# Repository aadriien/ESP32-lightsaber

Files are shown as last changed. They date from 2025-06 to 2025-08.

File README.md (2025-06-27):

# 🪐🤺 Lightsaber

## Description

Introducing... a homemade **lightsaber**, powered by an ESP32 microcontroller! 

This project is still a **work in progress**, so please hang tight while I get things going.

## How It Works

Start by clicking the joystick. This will activate the lightsaber with a cool sound effect (lightspeed)! 

Maneuver the joystick to move between colors. Once you've found a color you like, hold that spot / angle, and click the joystick as you would a button. Keep your ears open for a themed sound corresponding to that specific color! 

To change the blade's hue, angle the joystick button, give it another click, and you'll have returned to "color selection mode". 

When you're ready to deactivate the lightsaber, simply click the joystick again and watch as the lights recede. Listen closely for a message as you go!

## Electronics / Pieces

1. **ESP32-WROOM-32**: microcontroller (logic)
2. **Addressable LED strip (WS2812B)**: lightsaber blade
    - individual LED manipulation 
    - actuator — output
3. **Joystick module**: lightsaber (de)activation
    - range of x, y values to map (+ button)
    - sensor — input
4. **9V battery + clip**: power source
5. **Power supply module**: 5V / 3.3V output converter
6. **Others ad hoc**: cables, wires, resistors, etc

## Tools / Tech

1. **C++**: code running on device
2. **Python**: code to play themed sounds
    - connects via serial monitor
    - using `playsound` library
    - with `PyObjC` to run efficiently
3. **PlatformIO**: embedded development toolset
    - VS Code extension
    - cross-platform, cross-architecture
    - debugger, static analysis, unit testing, etc
    - project configs (build env, dependencies)

## Features

- **⭐️ Lightsaber (de)activation**: Exciting visual effects with sequential LEDs.
- **🎨 Customizable saber blade**: Highly flexible color wheel selection via joystick.

- **🔒 Color locking ability**: Option to hold selected color in place with joystick button.
- **🎵 Themed sound effects**: Music and phrases to match colors and saber (de)activation.

## Video Demos

Video demo of lightsaber activation and color selection

## Example Images

🎮 Wiring View   |   🌈 Lightsaber LED Strip   |   🔌 Wiring Above
:-------------------------:|:-------------------------:|:-------------------------:
Example image of front wiring view  |  Example image of saber LED strip  |  Example image of above wiring view

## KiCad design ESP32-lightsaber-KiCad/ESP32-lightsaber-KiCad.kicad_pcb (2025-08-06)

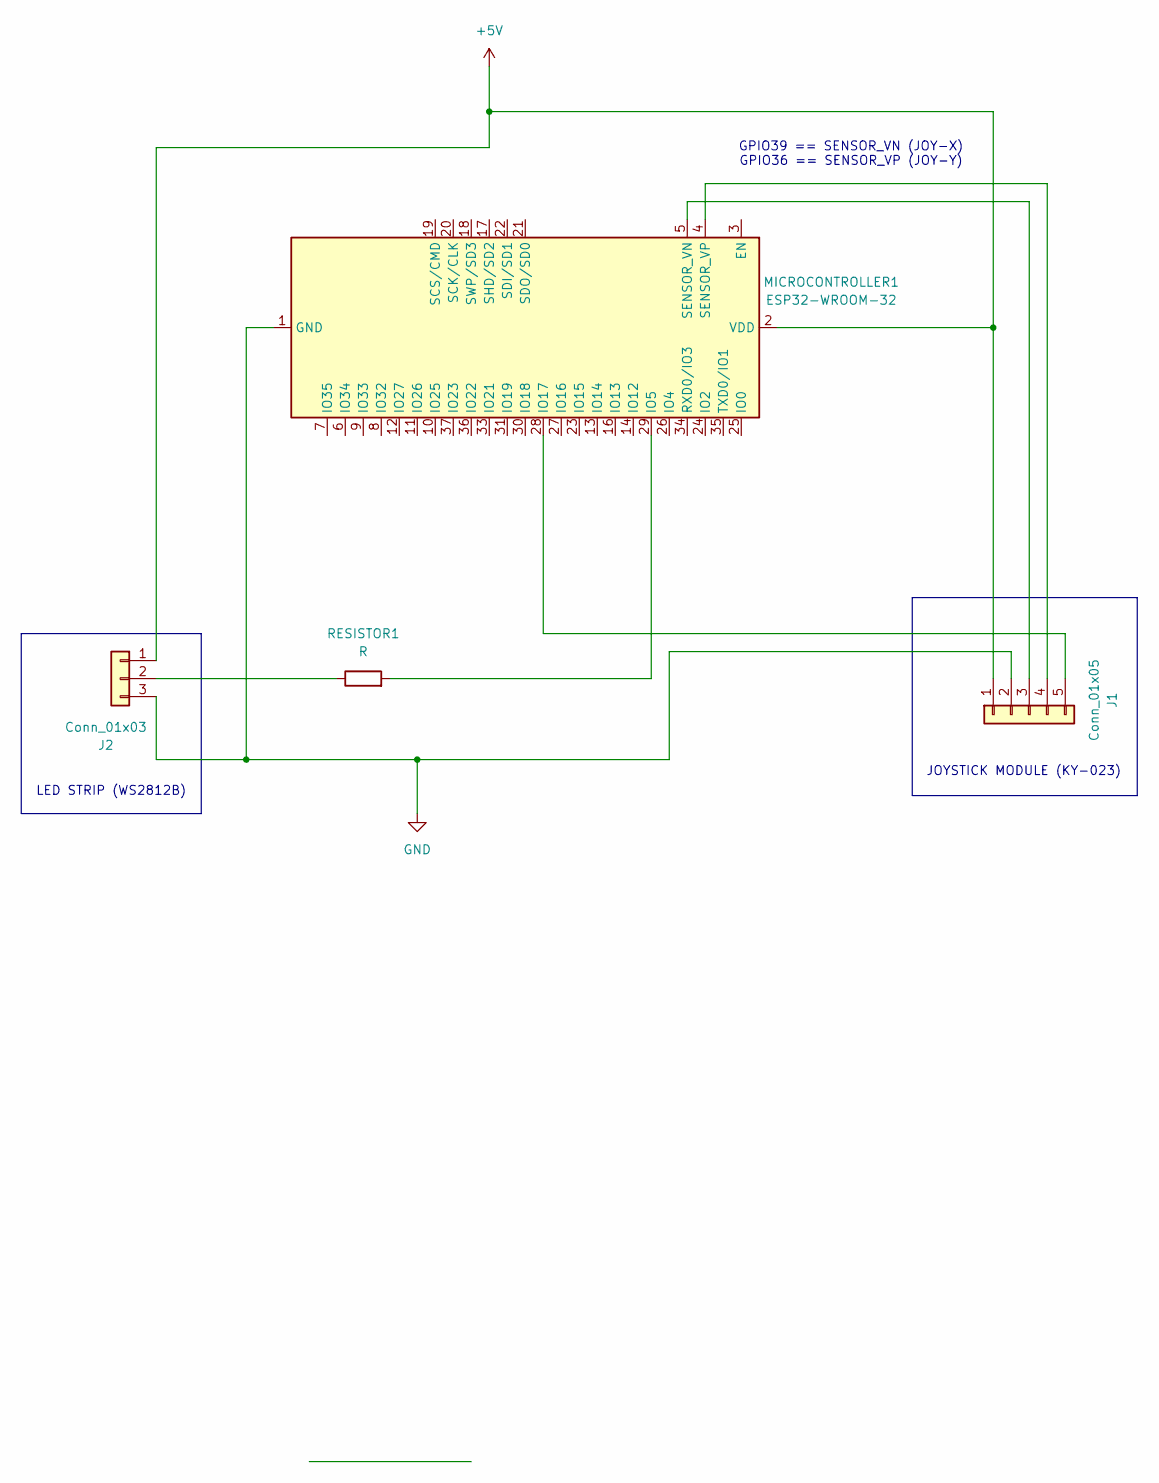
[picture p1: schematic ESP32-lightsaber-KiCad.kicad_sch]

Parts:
J1: Conn_01x05; PinHeader_1x05_P2.54mm_Vertical
J2: Conn_01x03; PinHeader_1x03_P2.54mm_Vertical
MICROCONTROLLER1: ESP32-WROOM-32
RESISTOR1: R; R_0805_2012Metric

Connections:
+5V: J1.1, J2.1, MICROCONTROLLER1.2 (VDD)
GND: J1.2, J2.3, MICROCONTROLLER1.1 (GND), MICROCONTROLLER1.15 (GND), MICROCONTROLLER1.38 (GND), MICROCONTROLLER1.39 (GND)
unnamed: J1.3, MICROCONTROLLER1.5 (SENSOR_VN)
unnamed: J1.4, MICROCONTROLLER1.4 (SENSOR_VP)
unnamed: J1.5, MICROCONTROLLER1.28 (IO17)
unnamed: J2.2, RESISTOR1.1
unnamed: MICROCONTROLLER1.29 (IO5), RESISTOR1.2

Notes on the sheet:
LED STRIP (WS2812B)
GPIO39 == SENSOR_VN (JOY-X) GPIO36 == SENSOR_VP (JOY-Y)
JOYSTICK MODULE (KY-023)

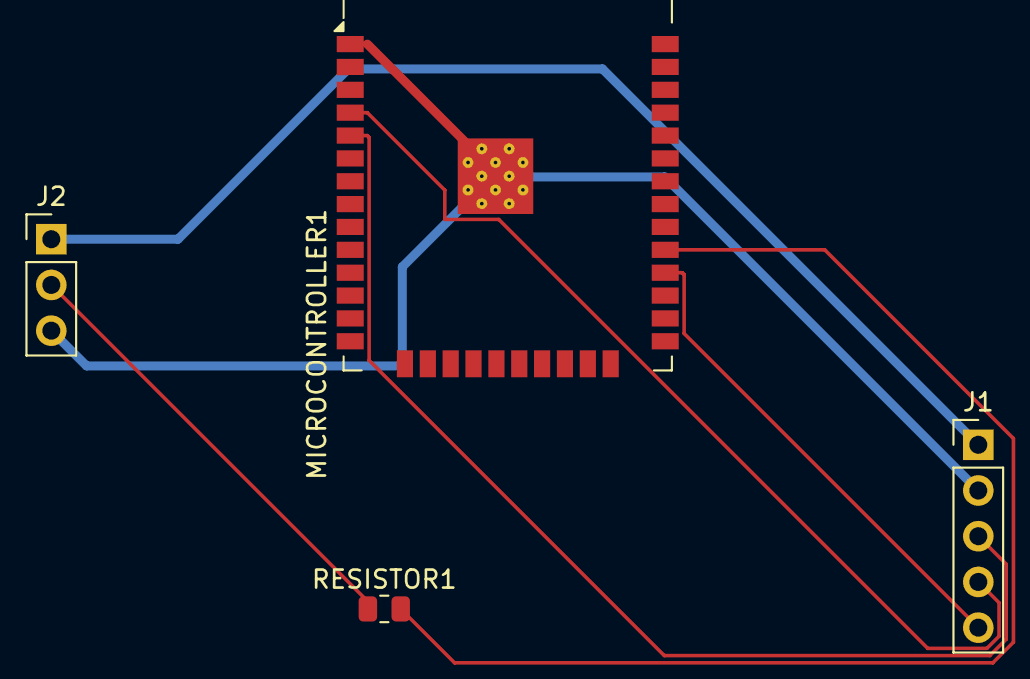
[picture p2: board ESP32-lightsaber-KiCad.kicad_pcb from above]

Board: 2 copper layers, 4 parts (0 on the bottom side), 7 nets.

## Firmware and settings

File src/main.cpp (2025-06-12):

// Lightsaber
// Animated lightsaber activation and deactivation, using ESP32.
// by Adrien Lynch

#include <FastLED.h>
#include <math.h>  // Needed for atan2 and sqrt in color selection

#if FASTLED_VERSION < 3001000
#error "Requires FastLED 3.1 or later; check github for latest code."
#endif

#define DATA_PIN    5
#define LED_TYPE    WS2812
#define COLOR_ORDER GRB
#define NUM_LEDS    60
#define BRIGHTNESS  255

#define JOY_X_PIN   39
#define JOY_Y_PIN   36
#define JOY_BUTTON_PIN 17

#define DEADZONE_RADIUS 400  // Joystick central zone (for color lock check)

CRGB leds[NUM_LEDS];
CRGB currentColor = CRGB::Blue;  // Default starting color

bool isActivated = false;
bool lastButtonState = HIGH;
bool colorLocked = false;


void printColor(const CRGB& color);
float getHueFromRGB(const CRGB& color);
const char* getNuancedColorName(const CRGB& color);
bool getColorFromJoystick(int joyX, int joyY, CRGB &outColor);
bool isJoystickOutsideDeadzone(int joyX, int joyY);
void checkClicked(int joyX, int joyY);
void activateLightsaber(CRGB color);
void deactivateLightsaber();



void setup() {
    Serial.begin(9600);
    delay(3000);  // Startup delay

    // Prep LEDs for output
    FastLED.addLeds<LED_TYPE, DATA_PIN, COLOR_ORDER>(leds, NUM_LEDS)
        .setCorrection(TypicalLEDStrip)
        .setDither(BRIGHTNESS < 255);
    FastLED.setBrightness(BRIGHTNESS);

    pinMode(JOY_BUTTON_PIN, INPUT_PULLUP);
}

void loop() {
    int joyX = analogRead(JOY_X_PIN);
    int joyY = analogRead(JOY_Y_PIN);
    
    checkClicked(joyX, joyY);

    // Read joystick changes & update color while lightsaber is ON
    if (isActivated) {
        if (!colorLocked) {
            CRGB newColor;
            if (getColorFromJoystick(joyX, joyY, newColor)) {
                currentColor = newColor;
                // Serial.println("Color updated");
            }
        }

        fill_solid(leds, NUM_LEDS, currentColor);
        FastLED.show();
    }

  delay(50);  // Smooth operation
}


void printColor(const CRGB& color) {
    Serial.print("Activated Color - R: ");
    Serial.print(color.r);
    Serial.print(" G: ");
    Serial.print(color.g);
    Serial.print(" B: ");
    Serial.println(color.b);
}


float getHueFromRGB(const CRGB& color) {
    float r = color.r / 255.0;
    float g = color.g / 255.0;
    float b = color.b / 255.0;

    float maxVal = max(r, max(g, b));
    float minVal = min(r, min(g, b));
    float delta = maxVal - minVal;

    if (delta < 0.00001) return 0;  // gray/white/black (no hue)

    float hue = 0;

    if (maxVal == r) {
        hue = 60.0 * fmod(((g - b) / delta), 6);
    } else if (maxVal == g) {
        hue = 60.0 * (((b - r) / delta) + 2);
    } else if (maxVal == b) {
        hue = 60.0 * (((r - g) / delta) + 4);
    }

    if (hue < 0) hue += 360;

    return hue;
}


const char* getNuancedColorName(const CRGB& color) {
    float hue = getHueFromRGB(color);

    float saturation = 
        (float)max(color.r, max(color.g, color.b)) 
        - 
        (float)min(color.r, min(color.g, color.b));
    saturation /= 255.0;

    float brightness = max(color.r, max(color.g, color.b)) / 255.0;

    // Handle black/white/gray first
    if (brightness < 0.1) return "Black";
    if (saturation < 0.1 && brightness > 0.9) return "White";
    if (saturation < 0.1) return "Gray";

    // Hue ranges with more nuance:
    if (hue >= 0 && hue < 15) return "Red";
    if (hue >= 15 && hue < 45) return "Orange";
    if (hue >= 45 && hue < 70) return "Yellow";
    if (hue >= 70 && hue < 150) return "Green";
    if (hue >= 150 && hue < 190) return "Cyan";
    if (hue >= 190 && hue < 260) return "Blue";
    if (hue >= 260 && hue < 320) return "Purple";
    if (hue >= 320 && hue < 345) return "Magenta";
    if (hue >= 345 && hue <= 360) return "Red";

    return "Unknown";
}



bool getColorFromJoystick(int joyX, int joyY, CRGB &outColor) {
    int centerX = 2048;
    int centerY = 2048;

    int dx = joyX - centerX;
    int dy = centerY - joyY;

    float distance = sqrt(dx * dx + dy * dy);
    float maxDistance = 2048.0;
    float normDist = distance / maxDistance;

    // Only update color if joystick button pushed enough
    if (normDist < 0.2) {
        return false;  // Stay with last color
    }

    // Calculate color wheel presentation based on joystick X/Y
    float angle = atan2(dy, dx);
    if (angle < 0) angle += 2 * PI;

    uint8_t hue = map((int)(angle * 180 / PI), 0, 360, 0, 255);
    uint8_t saturation = constrain(normDist * 255, 0, 255);
    uint8_t brightness = 255;

    outColor = CHSV(hue, saturation, brightness);
    return true;
}


bool isJoystickOutsideDeadzone(int joyX, int joyY) {
    // Ensure we don't get stuck in default white color while joystick centered
    int centerX = 2048;
    int centerY = 2048;
    
    int dx = joyX - centerX;
    int dy = joyY - centerY;
    
    int distSq = dx*dx + dy*dy;
    return distSq > (DEADZONE_RADIUS * DEADZONE_RADIUS);
}


void checkClicked(int joyX, int joyY) {
    static bool lastButtonState = HIGH;
    bool currentButtonState = digitalRead(JOY_BUTTON_PIN);

    if (lastButtonState == HIGH && currentButtonState == LOW) {
        if (!isActivated) {
            // Trigger sound on activation
            Serial.println("Play EVENT: activated");
            delay(1000);

            // Turn on lightsaber
            activateLightsaber(currentColor);
            isActivated = true;
            colorLocked = false;
            
            Serial.println("Lightsaber activated!");
            printColor(currentColor);
        } 
        else {
            // Lightsaber is on: toggle color lock if joystick pushed
            if (isJoystickOutsideDeadzone(joyX, joyY)) {
                colorLocked = !colorLocked;
                
                Serial.println(colorLocked ? "Color locked!" : "Color unlocked!");
                if (colorLocked) {
                    printColor(currentColor);

                    // Print basic color name for sound triggers
                    Serial.print("Play COLOR: ");
                    Serial.println(getNuancedColorName(currentColor));
                }
            } 
            else {
                // Trigger sound on deactivation
                Serial.println("Play EVENT: deactivated");

                // Otherwise, turn off lightsaber
                deactivateLightsaber();
                isActivated = false;
                colorLocked = false;
                
                Serial.println("Lightsaber deactivated!");
            }
        }
    }
    lastButtonState = currentButtonState;
}


void activateLightsaber(CRGB color) {
    for (int i = 0; i < NUM_LEDS; i++) {
        leds[i] = color;
        FastLED.show();
        delay(20);
    }
}


void deactivateLightsaber() {
    for (int i = NUM_LEDS - 1; i >= 0; i--) {
        leds[i] = CRGB::Black;
        FastLED.show();
        delay(20);
    }
}

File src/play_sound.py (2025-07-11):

import os
import serial
from playsound import playsound

BASE_DIR = os.path.dirname(os.path.abspath(__file__))


# Map color names & event flags to sound file paths 
color_sounds = {
    "red": "media/darth-vader.mp3",
    "orange": "media/obi-wan.mp3",
    "yellow": "media/jar-jar.mp3",
    "green": "media/yoda.mp3",
    "cyan": "media/x-wing.mp3",
    "blue": "media/luke-skywalker.mp3",
    "purple": "media/WEEEEEOW.mp3",
    "magenta": "media/tie-fighter.mp3",
    "black": "media/tie-fighter.mp3",
    "white": "media/x-wing.mp3",
    "gray": "media/r2d2.mp3",
}

event_sounds = {
    "activated": "media/lightspeed.mp3",
    "deactivated": "media/c3po.mp3",
}


def main():
    # ESP32 port plugged in
    ser = serial.Serial('/dev/cu.usbserial-0001', 9600)

    while True:
        line = ser.readline().decode('utf-8').strip()
        print("Received from serial:", line)
        
        sound_file = None
        source = None

        if line.startswith("Play COLOR:"):
            color = line.split("Play COLOR:")[1].strip().lower()
            sound_file = color_sounds.get(color)
            source = f"color '{color}'"

        elif line.startswith("Play EVENT:"):
            event = line.split("Play EVENT:")[1].strip().lower()
            sound_file = event_sounds.get(event)
            source = f"event '{event}'"

        if sound_file:
            print(f"Playing sound for {source}: {sound_file}")
            full_path = os.path.join(BASE_DIR, sound_file)
            playsound(full_path)
        else:
            print(f"No sound mapped for {source}")


if __name__ == "__main__":
    main()

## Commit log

2025-06-12 Fixed indentation following migration
    [main.cpp]
2025-07-11 Drafted KiCad schematic for lightsaber circuitry
    [ESP32-lightsaber-KiCad.kicad_pcb, ESP32-lightsaber-KiCad.kicad_sch]
2025-07-19 Drafted PCB prototype in KiCad from schematic
    [ESP32-lightsaber-KiCad.kicad_pcb, ESP32-lightsaber-KiCad.kicad_sch]
2025-08-06 Modified lightsaber schematic & PCB following prototype feedback
    [ESP32-lightsaber-KiCad.kicad_pcb, ESP32-lightsaber-KiCad.kicad_sch]
2025-08-06 Thickened wires for 5V+ power & GND in PCB prototype for current flow
    [ESP32-lightsaber-KiCad.kicad_pcb]
